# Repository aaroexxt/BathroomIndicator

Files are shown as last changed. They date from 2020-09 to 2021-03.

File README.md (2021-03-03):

# BathroomIndicator
 BLISS - Bathroom Location and Indication Security System aka an overcomplicated way to prevent accidental walk-ins, and a great PCB learning project!

## Design Intent
I built this mostly to practice my PCB design and layout skills, but it's actually quite cool in person. Basically, it's designed to be a comprehensive system for people who have to share space to have a way to tell others that they're busy. I've installed a set of these on a bathroom I share with my sister (who thought that was a good idea?) so that we can both know when somebody else is using the bathroom.

## Pictures

Version 1
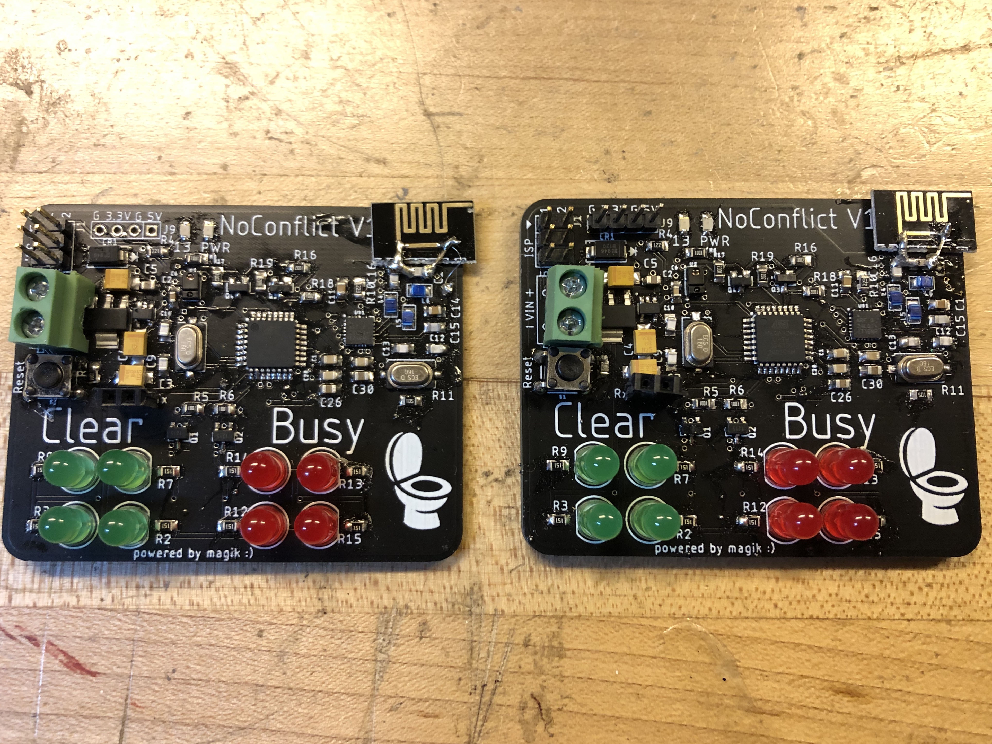
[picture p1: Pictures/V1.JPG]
Version 1


Version 2
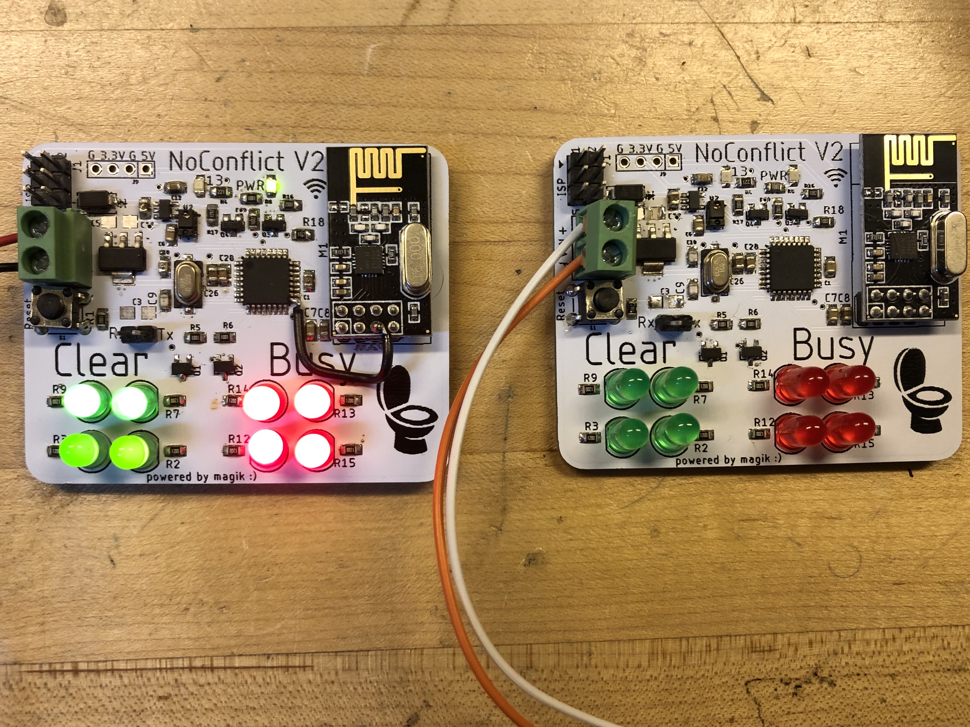
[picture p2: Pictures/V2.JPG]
Version 2


## Renderings

Top - Version 2
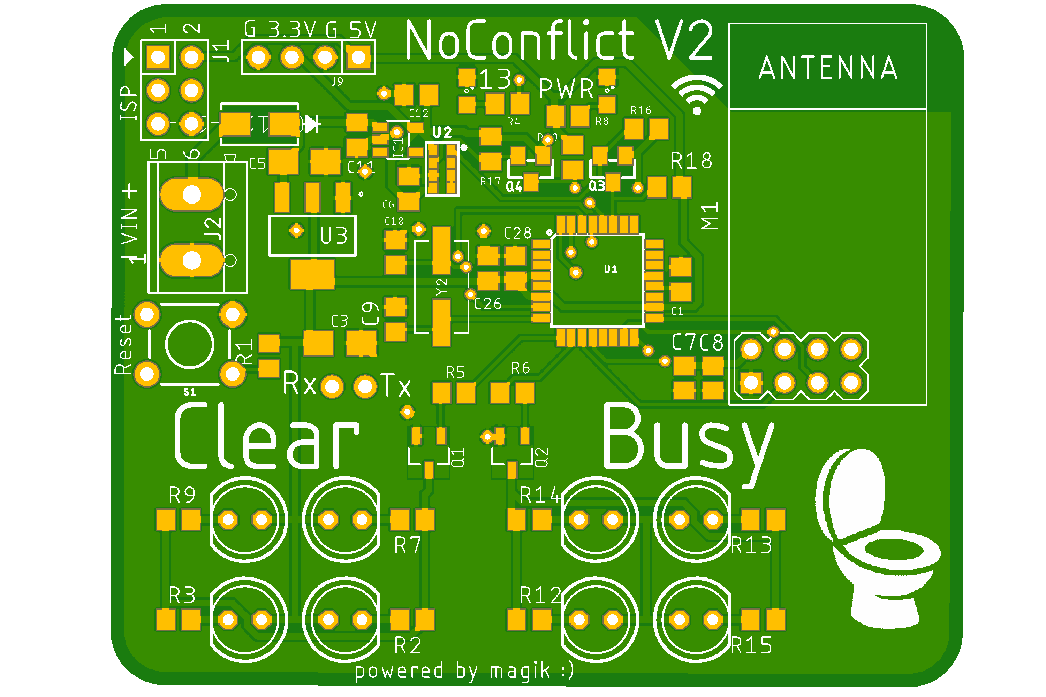
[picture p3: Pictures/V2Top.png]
Version 2 Top


Bottom - Version 2
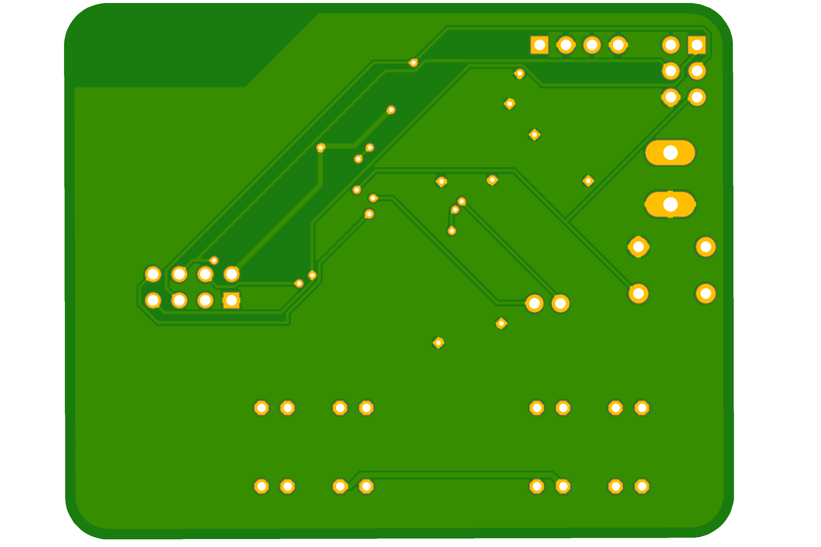
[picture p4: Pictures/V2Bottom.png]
Version 2 Bottom


### Design Notes

The major difference between versions 1 and 2 is that Version 1 had a custom radio based on the NRF24L01+ radio by Nordic Semiconductor, while this was replaced with a premade module in Version 2 because of my lack of experience with antenna design (1 foot range on my custom one vs _30_ feet on the premade module). Other than that, it worked well. I also had some issues with the 3.3v regulator schematic in V1 (incorrect schematic for EN pin) but this was solved in version 2.

### By Aaron Becker

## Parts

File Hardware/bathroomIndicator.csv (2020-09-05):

Qty | Value | Device | Package | Parts | Description | ARROW_ELECTRONICS-PURCHASE-URL | AUTOMOTIVE | AVAILABILITY | BUILT_BY | CENTROID_NOT_SPECIFIED | COLLECTOR_BASE_VOLTAGE | COLLECTOR_EMITTER_BREAKDOWN_VOLTAGE | COLLECTOR_EMITTER_SATURATION_VOLTAGE | COLLECTOR_EMITTER_VOLTAGE | DATASHEET | DESCRIPTION | DEVICE_CLASS_L1 | DEVICE_CLASS_L2 | DEVICE_CLASS_L3 | DIGIKEY-PURCHASE-URL | DIGIKEY_DESCRIPTION | DIGIKEY_PART_NUMBER | EMITTER_BASE_VOLTAGE | FOOTPRINT_PARAMETERS_1 | FOOTPRINT_PARAMETERS_2 | FOOTPRINT_PARAMETERS_3 | FOOTPRINT_VARIANT_NAME_0 | FOOTPRINT_VARIANT_NAME_1 | FOOTPRINT_VARIANT_NAME_2 | FOOTPRINT_VARIANT_NAME_3 | HEIGHT | HFE_MAX | HFE_MIN | HFE_TESTIC | HFE_TESTVCE | IPC_LAND_PATTERN_NAME | LEAD_FREE | MANUFACTURER_PART_NUMBER | MAX_COLLECTOR_CURRENT | MAX_JUNCTION_TEMP | MF | MFG_PACKAGE_IDENT | MFG_PACKAGE_IDENT_COMPONENT_ID | MFG_PACKAGE_IDENT_DATE | MFG_PACKAGE_IDENT_REV | MOUSER-PURCHASE-URL | MOUSER_DESCRIPTION | MOUSER_PART_NUMBER | MP | MPN | NUMBER_OF_ELEMENTS | NUMBER_OF_NPN | OC_FARNELL | OC_NEWARK | PACKAGE | POPULARITY | POWER_DISSIPATION | PREFIX | PRICE
1 |  | HEADER-1X2ROUND | 1X02_ROUND | JP1 | PIN HEADER
8 |  | LED5MM | LED5MM | LED1, LED2, LED5, LED6, LED7, LED8, LED9, LED10 | LED |  |  |  |  |  |  |  |  |  |  |  |  |  |  |  |  |  |  |  |  |  |  |  |  |  |  |  |  |  |  |  |  |  |  |  |  |  |  |  |  |  |  |  |  |  |  |  |  |  |  | 93
2 |  | LEDSML0805 | SML0805 | LED3, LED4 | LED |  |  |  |  |  |  |  |  |  |  |  |  |  |  |  |  |  |  |  |  |  |  |  |  |  |  |  |  |  |  |  |  |  |  |  |  |  |  |  |  |  |  |  |  |  |  |  |  |  |  | 17
4 | 0.1uF | C-USC0805 | C0805 | C1, C6, C8, C28 | CAPACITOR, American symbol |  |  |  |  |  |  |  |  |  |  |  |  |  |  |  |  |  |  |  |  |  |  |  |  |  |  |  |  |  |  |  |  |  |  |  |  |  |  |  |  |  |  |  |  |  |  |  |  |  |  | 63
1 | 1 uF | C-USC0805 | C0805 | C11 | CAPACITOR, American symbol |  |  |  |  |  |  |  |  |  |  |  |  |  |  |  |  |  |  |  |  |  |  |  |  |  |  |  |  |  |  |  |  |  |  |  |  |  |  |  |  |  |  |  |  |  |  |  |  |  |  | 63
5 | 10k | R-US_R0805 | R0805 | R1, R16, R17, R18, R19 | RESISTOR, American symbol |  |  |  |  |  |  |  |  |  |  |  |  |  |  |  |  |  |  |  |  |  |  |  |  |  |  |  |  |  |  |  |  |  |  |  |  |  |  |  |  |  |  |  |  |  |  |  |  |  |  | 85
2 | 10uF | CPOL-USB/3528-21W | B/3528-21W | C3, C5 | POLARIZED CAPACITOR, American symbol |  |  |  |  |  |  |  |  |  |  |  |  |  |  |  |  |  |  |  |  |  |  |  |  |  |  |  |  |  |  |  |  |  |  |  |  |  |  |  |  |  |  |  |  |  |  |  |  |  |  | 3
8 | 120 | R-US_R0805 | R0805 | R2, R3, R7, R9, R12, R13, R14, R15 | RESISTOR, American symbol |  |  |  |  |  |  |  |  |  |  |  |  |  |  |  |  |  |  |  |  |  |  |  |  |  |  |  |  |  |  |  |  |  |  |  |  |  |  |  |  |  |  |  |  |  |  |  |  |  |  | 85
3 | 1k | R-US_R0805 | R0805 | R5, R6, R8 | RESISTOR, American symbol |  |  |  |  |  |  |  |  |  |  |  |  |  |  |  |  |  |  |  |  |  |  |  |  |  |  |  |  |  |  |  |  |  |  |  |  |  |  |  |  |  |  |  |  |  |  |  |  |  |  | 85
2 | 1uF | C-USC0805 | C0805 | C7, C26 | CAPACITOR, American symbol |  |  |  |  |  |  |  |  |  |  |  |  |  |  |  |  |  |  |  |  |  |  |  |  |  |  |  |  |  |  |  |  |  |  |  |  |  |  |  |  |  |  |  |  |  |  |  |  |  |  | 63
1 | 2.2 uF | C-USC0805 | C0805 | C12 | CAPACITOR, American symbol |  |  |  |  |  |  |  |  |  |  |  |  |  |  |  |  |  |  |  |  |  |  |  |  |  |  |  |  |  |  |  |  |  |  |  |  |  |  |  |  |  |  |  |  |  |  |  |  |  |  | 63
2 | 20pF | C-USC0805 | C0805 | C9, C10 | CAPACITOR, American symbol |  |  |  |  |  |  |  |  |  |  |  |  |  |  |  |  |  |  |  |  |  |  |  |  |  |  |  |  |  |  |  |  |  |  |  |  |  |  |  |  |  |  |  |  |  |  |  |  |  |  | 63
1 | 220 | R-US_R0805 | R0805 | R4 | RESISTOR, American symbol |  |  |  |  |  |  |  |  |  |  |  |  |  |  |  |  |  |  |  |  |  |  |  |  |  |  |  |  |  |  |  |  |  |  |  |  |  |  |  |  |  |  |  |  |  |  |  |  |  |  | 85
1 | APDS-9960 | APDS-9960 | APDS-9960 | U2 | Avago APDS-9960 Digital Proximity, Ambient Light, RGB, and Gesture Sensor.
1 | ATMEGA328P_TQFP | ATMEGA328P_TQFP | TQFP32-08 | U1 | Popular 328P in QFP
1 | B120-13-F | B120-13-F | SMA_DIO | CR1 |  |  |  |  | EMA_UL_Team |  |  |  |  |  |  |  |  |  |  |  |  |  |  |  |  |  |  |  |  |  |  |  |  |  |  |  |  | B120-13-F
2 | BSS138 | MOSFET-NWIDE | SOT23-WIDE | Q3, Q4 | N-Channel Mosfet
1 | CON_HEADER_1X04 | CON_HEADER_1X04 | M1X4 | J9
1 | CON_HEADER_PRG_AVR_ICSP-PTH | CON_HEADER_PRG_AVR_ICSP-PTH | HEADER_PRG_2X03 | J1 | 2x3 AVR ICSP programming header
1 | CON_TERMINAL_BLOCK_02-5MM | CON_TERMINAL_BLOCK_02-5MM | TERMINAL_BLOCK_2P_5 | J2 | 2 poles wire to board terminal block
1 | ECS-160-20-3X-TR | ECS-160-20-3X-TR | XTAL_ECS-160-20-3X-TR | Y2 | SMD QUARTZ CRYSTAL | https://snapeda.com/shop?store=Arrow+Electronics&id=561589 |  | Unavailable |  |  |  |  |  |  |  | 16MHz ±30ppm Crystal 20pF 50 Ohms HC-49/US |  |  |  | https://snapeda.com/shop?store=DigiKey&id=561589 |  |  |  |  |  |  |  |  |  |  |  |  |  |  |  |  |  |  |  |  | ECS Inc. |  |  |  |  | https://snapeda.com/shop?store=Mouser&id=561589 |  |  | ECS-160-20-3X-TR |  |  |  |  |  | HC49/US ECS International |  |  |  | None
1 | MOMENTARY-SWITCH-SPST-PTH-6.0MM | MOMENTARY-SWITCH-SPST-PTH-6.0MM | TACTILE_SWITCH_PTH_6.0MM | S1 | Momentary Switch (Pushbutton) - SPST
1 | NCP1117ST50T3G | NCP1117ST50T3G | SOT230P700X180-4N | U3 | 1.0 A Low-Dropout Positive ,Fixed and Adjustable,Voltage Regulators |  |  | Unavailable |  |  |  |  |  |  |  | Linear Voltage Regulator IC 1 Output 1A SOT-223 |  |  |  | https://snapeda.com/shop?store=DigiKey&id=836318 |  |  |  |  |  |  |  |  |  |  |  |  |  |  |  |  |  |  |  |  | ON Semiconductor |  |  |  |  | https://snapeda.com/shop?store=Mouser&id=836318 |  |  | NCP1117ST50T3G |  |  |  |  |  | SOT-223 ON Semiconductor |  |  |  | None
2 | STMICROELECTRONICS_2STR1215STMICROELECTRONICS_2STR1215_0_0 | STMICROELECTRONICS_2STR1215STMICROELECTRONICS_2STR1215_0_0 | STMICROELECTRONICS_2STR1215_0 | Q1, Q2 | Bipolar (BJT) Transistor NPN 15V 1.5A 500mW Surface Mount SOT-23-3 |  | No |  |  | No | 15V | 15V | 0.4V | 15V | https://www.st.com/resource/en/datasheet/2str1215.pdf |  | Discrete Semiconductors | Transistors | BJTs |  | TRANS NPN 15V 1.5A SOT-23 | 497-6205-1-ND | 5V | {fp_type":"SOT23","params":{"N":{"default":"3","long name":"Number of leads","type":"multichoice","short name":"N"},"A":{"nom":false,"long name":"Height","min":false,"max":1250000,"short name":"A","type":"measurement"},"A1":{"nom":75000,"long name":"Package clearance","min":0,"max":150000,"short name":"A1","type":"measurement"},"A2":{"nom":1100000,"long name":"Package height","min":1000000,"max":1200000,"short name":"A2","type":"measurement"},"D":{"nom":2926000,"long name":"Package length","min":2826000,"max":3026000,"short name":"D","type":"measurement"},"E":{"nom":2800000,"long name":"Width /w leads","min":2600000,"max":3000000,"short name":"E","type":"measurement"},"E1":{"nom":1625000,"long name":"Package width","min":1526000,"max":1726000,"short name":"E1","type":"measurement"},"B":{"nom":430000,"long name":"Lead width","min":360000,"max":500000,"short name":"B","type":"measurement"},"C":{"nom":170000,"long name":"Lead thickness","min":140000,"max":200000,"short name":"C","type":"measurement"},"L":{"nom":450000,"long name":"Lead foot length","min":350000,"max":600000,"short name":"L","type":"measurement"},"e":{"nom":950000,"long name":"Lead pitch","min":null,"max":null,"short name":"e","type":"measurement"},"PHI":{"nom":false,"long name":"Lead angle","min":0,"max":8000000,"short name":"PHI","type":"measurement"},"offset x":{"nom":0,"long name":"X Center offset","min":null,"max":null,"short name":"offset x","type":"measurement"},"offset y":{"nom":0,"long name":"Y Center 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 | {fp_type":"SOT23","params":{"N":{"default":"3","long name":"Number of leads","type":"multichoice","short name":"N"},"A":{"nom":false,"long name":"Height","min":false,"max":1250000,"short name":"A","type":"measurement"},"A1":{"nom":75000,"long name":"Package clearance","min":0,"max":150000,"short name":"A1","type":"measurement"},"A2":{"nom":1100000,"long name":"Package height","min":1000000,"max":1200000,"short name":"A2","type":"measurement"},"D":{"nom":2926000,"long name":"Package length","min":2826000,"max":3026000,"short name":"D","type":"measurement"},"E":{"nom":2800000,"long name":"Width /w leads","min":2600000,"max":3000000,"short name":"E","type":"measurement"},"E1":{"nom":1625000,"long name":"Package width","min":1526000,"max":1726000,"short name":"E1","type":"measurement"},"B":{"nom":430000,"long name":"Lead width","min":360000,"max":500000,"short name":"B","type":"measurement"},"C":{"nom":170000,"long name":"Lead thickness","min":140000,"max":200000,"short name":"C","type":"measurement"},"L":{"nom":450000,"long name":"Lead foot length","min":350000,"max":600000,"short name":"L","type":"measurement"},"e":{"nom":950000,"long name":"Lead pitch","min":null,"max":null,"short name":"e","type":"measurement"},"PHI":{"nom":false,"long name":"Lead angle","min":0,"max":8000000,"short name":"PHI","type":"measurement"},"offset x":{"nom":0,"long name":"X Center offset","min":null,"max":null,"short name":"offset x","type":"measurement"},"offset y":{"nom":0,"long name":"Y Center 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 | {fp_type":"SOT23","params":{"N":{"default":"3","long name":"Number of leads","type":"multichoice","short name":"N"},"A":{"nom":false,"long name":"Height","min":false,"max":1250000,"short name":"A","type":"measurement"},"A1":{"nom":75000,"long name":"Package clearance","min":0,"max":150000,"short name":"A1","type":"measurement"},"A2":{"nom":1100000,"long name":"Package height","min":1000000,"max":1200000,"short name":"A2","type":"measurement"},"D":{"nom":2926000,"long name":"Package length","min":2826000,"max":3026000,"short name":"D","type":"measurement"},"E":{"nom":2800000,"long name":"Width /w leads","min":2600000,"max":3000000,"short name":"E","type":"measurement"},"E1":{"nom":1625000,"long name":"Package width","min":1526000,"max":1726000,"short name":"E1","type":"measurement"},"B":{"nom":430000,"long name":"Lead width","min":360000,"max":500000,"short name":"B","type":"measurement"},"C":{"nom":170000,"long name":"Lead thickness","min":140000,"max":200000,"short name":"C","type":"measurement"},"L":{"nom":450000,"long name":"Lead foot length","min":350000,"max":600000,"short name":"L","type":"measurement"},"e":{"nom":950000,"long name":"Lead pitch","min":null,"max":null,"short name":"e","type":"measurement"},"PHI":{"nom":false,"long name":"Lead angle","min":0,"max":8000000,"short name":"PHI","type":"measurement"},"offset x":{"nom":0,"long name":"X Center offset","min":null,"max":null,"short name":"offset x","type":"measurement"},"offset y":{"nom":0,"long name":"Y Center 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 | Recommended_Land_Pattern | IPC_A | IPC_B | IPC_C | 1.25mm | 560 | 200 | 0.5A | 2V | SOT95P280X125-3 | Yes |  | 1.5A | +150°C | STMicroelectronics | SOT23_8162275 | 8e1c602943959e66 | 0 | 3 |  | Bipolar Transistors - BJT Lo Vltg FAST SWITCH Hi GAIN PNP | 511-2STR1215 |  | 2STR1215 | 1 | 1 |  |  | SOT-23 |  | 0.5W | Q
1 | TPS70933DBV | TPS70933DBV | SOT23-5 | IC1 | TPS709xx 150-mA, 30-V, 1-μA IQ Voltage Regulators with Enable |  |  |  |  |  |  |  |  |  |  |  |  |  |  |  |  |  |  |  |  |  |  |  |  |  |  |  |  |  |  |  |  |  |  |  | Texas Instruments |  |  |  |  |  |  |  |  | TPS70933DBVT |  |  | 2382995 | 37X8895
1 | WIRELESS-NRF24L01 | WIRELESS-NRF24L01 | WIRELESS-NRF24L01 | M1 | 2.4 GHz Wireless Module based on NRF24L01 chip
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

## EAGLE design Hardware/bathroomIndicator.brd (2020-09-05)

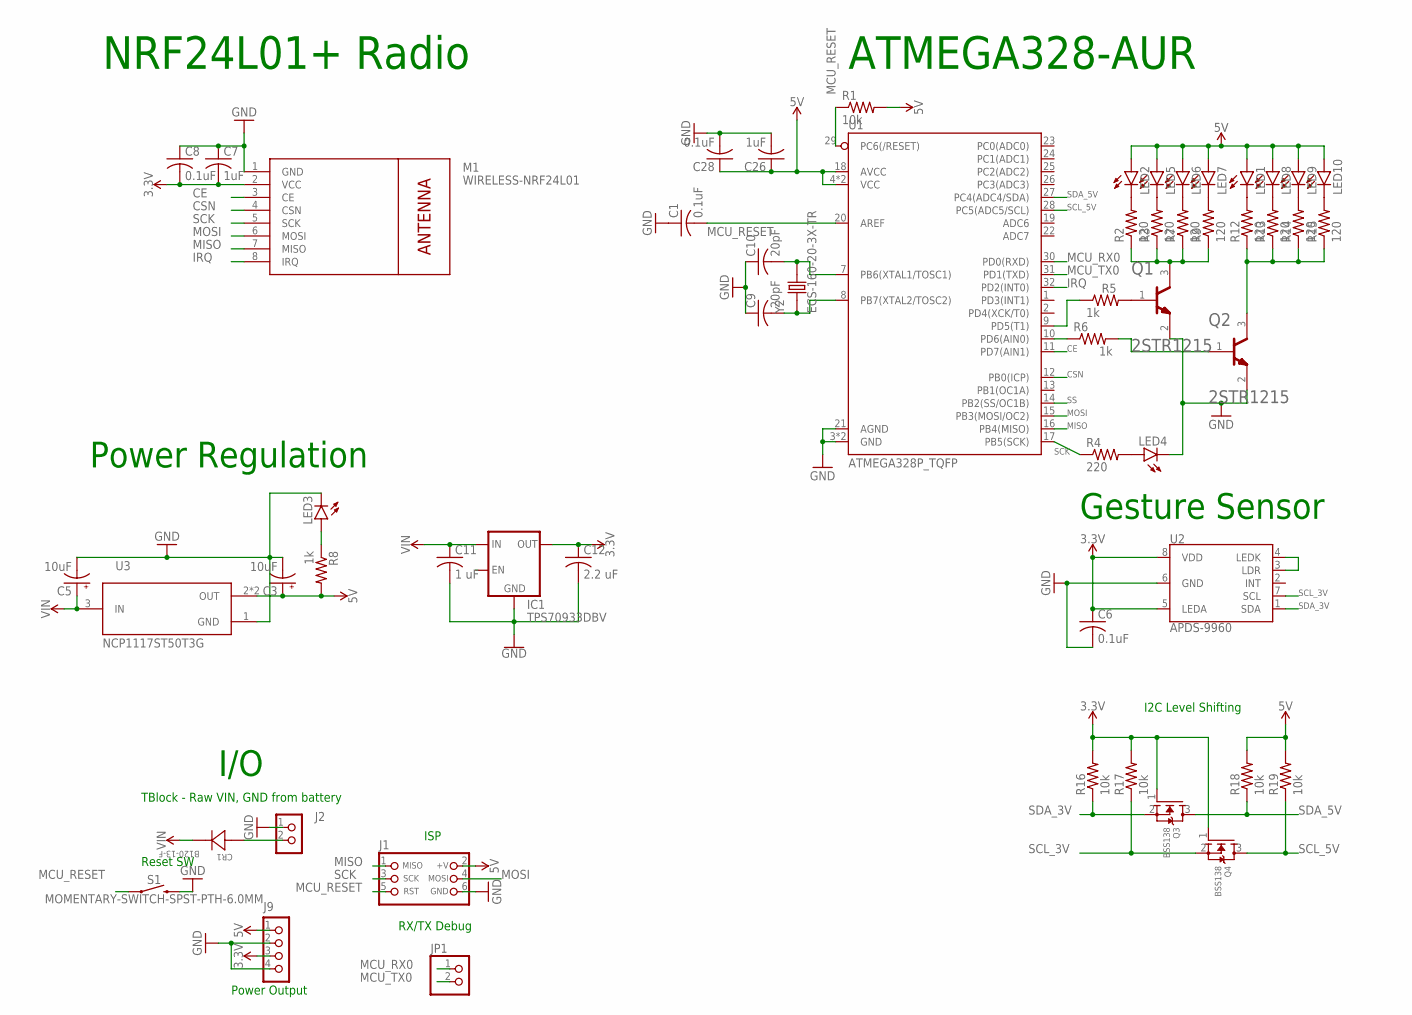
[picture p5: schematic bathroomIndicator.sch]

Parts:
C1, C6, C8, C28: 0.1uF; C0805
C3, C5: 10uF; B/3528-21W
C7, C26: 1uF; C0805
C9, C10: 20pF; C0805
C11: 1 uF; C0805
C12: 2.2 uF; C0805
CR1: B120-13-F; SMA_DIO
IC1: TPS70933DBV; SOT23-5
J1: CON_HEADER_PRG_AVR_ICSP-PTH; HEADER_PRG_2X03
J2: CON_TERMINAL_BLOCK_02-5MM; TERMINAL_BLOCK_2P_5
J9: CON_HEADER_1X04; M1X4
JP1: HEADER-1X2ROUND; 1X02_ROUND
LED1, LED2, LED5, LED6, LED7, LED8, LED9, LED10: LED5MM
LED3, LED4: LEDSML0805; SML0805
M1: WIRELESS-NRF24L01
Q1, Q2: STMICROELECTRONICS_2STR1215STMICROELECTRONICS_2ST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; STMICROELECTRONICS_2STR1215_0
Q3, Q4: BSS138; SOT23-WIDE
R1, R16, R17, R18, R19: 10k; R0805
R2, R3, R7, R9, R12, R13, R14, R15: 120; R0805
R4: 220; R0805
R5, R6, R8: 1k; R0805
S1: MOMENTARY-SWITCH-SPST-PTH-6.0MM; TACTILE_SWITCH_PTH_6.0MM
U1: ATMEGA328P_TQFP; TQFP32-08
U2: APDS-9960
U3: NCP1117ST50T3G; SOT230P700X180-4N
Y2: ECS-160-20-3X-TR; XTAL_ECS-160-20-3X-TR

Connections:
3.3V: C6.1, C7.2, C8.2, C12.1, IC1.5 (OUT), J9.3, M1.2 (VCC), Q3.1 (G), Q4.1 (G), R16.2, R17.2, U2.5 (LEDA), U2.8 (VDD)
5V: C3.+, C26.1, C28.1, J1.2 (+V), J9.1, LED1.A, LED2.A, LED5.A, LED6.A, LED7.A, LED8.A, LED9.A, LED10.A, R1.2, R8.2, R18.2, R19.2, U1.4 (VCC), U1.6 (VCC), U1.18 (AVCC), U3.2 (OUT), U3.4 (OUT)
CE: M1.3 (CE), U1.11 (PD7(AIN1))
CSN: M1.4 (CSN), U1.12 (PB0(ICP))
GND: C1.1, C3.-, C5.-, C6.2, C7.1, C8.1, C9.1, C10.1, C11.2, C12.2, C26.2, C28.2, IC1.2 (GND), J1.6 (GND), J2.1, J9.2, J9.4, LED3.C, LED4.C, M1.1 (GND), Q1.2 (E), Q2.2 (E), S1.3 (2), U1.3 (GND), U1.5 (GND), U1.21 (AGND), U2.6 (GND), U3.1 (GND)
IRQ: M1.8 (IRQ), U1.32 (PD2(INT0))
MCU_RESET: J1.5 (RST), R1.1, S1.1, U1.29 (PC6(/RESET))
MCU_RX0: JP1.1, U1.30 (PD0(RXD))
MCU_TX0: JP1.2, U1.31 (PD1(TXD))
MISO: J1.1 (MISO), M1.7 (MISO), U1.16 (PB4(MISO))
MOSI: J1.4 (MOSI), M1.6 (MOSI), U1.15 (PB3(MOSI/OC2))
unnamed: LED2.K (C), R2.2
unnamed: LED5.K (C), R3.2
unnamed: C1.2, U1.20 (AREF)
unnamed: LED6.K (C), R7.2
unnamed: R5.1, U1.9 (PD5(T1))
unnamed: LED7.K (C), R9.2
unnamed: LED4.A, R4.2
unnamed: Q2.1 (B), R6.2
unnamed: R6.1, U1.10 (PD6(AIN0))
unnamed: LED3.A, R8.1
unnamed: Q1.1 (B), R5.2
unnamed: C9.2, U1.8 (PB7(XTAL2/TOSC2)), Y2.1
unnamed: C10.2, U1.7 (PB6(XTAL1/TOSC1)), Y2.2
unnamed: U2.3 (LDR), U2.4 (LEDK)
unnamed: LED1.K (C), R12.2
unnamed: LED8.K (C), R13.2
unnamed: LED9.K (C), R14.2
unnamed: LED10.K (C), R15.2
unnamed: Q1.3 (C), R2.1, R3.1, R7.1, R9.1
unnamed: Q2.3 (C), R12.1, R13.1, R14.1, R15.1
unnamed: CR1.2, J2.2
SCK: J1.3 (SCK), M1.5 (SCK), R4.1, U1.17 (PB5(SCK))
SCL_3V: Q4.2 (S), R17.1, U2.7 (SCL)
SCL_5V: Q4.3 (D), R19.1, U1.28 (PC5(ADC5/SCL))
SDA_3V: Q3.2 (S), R16.1, U2.1 (SDA)
SDA_5V: Q3.3 (D), R18.1, U1.27 (PC4(ADC4/SDA))
SS: U1.14 (PB2(SS/OC1B))
VIN: C5.+, C11.1, CR1.1, IC1.1 (IN), U3.3 (IN)

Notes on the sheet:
TBlock - Raw VIN, GND from battery
NRF24L01+ Radio
ATMEGA328-AUR
Power Regulation
I/O
Gesture Sensor
I2C Level Shifting
RX/TX Debug
ISP
Reset SW
Power Output

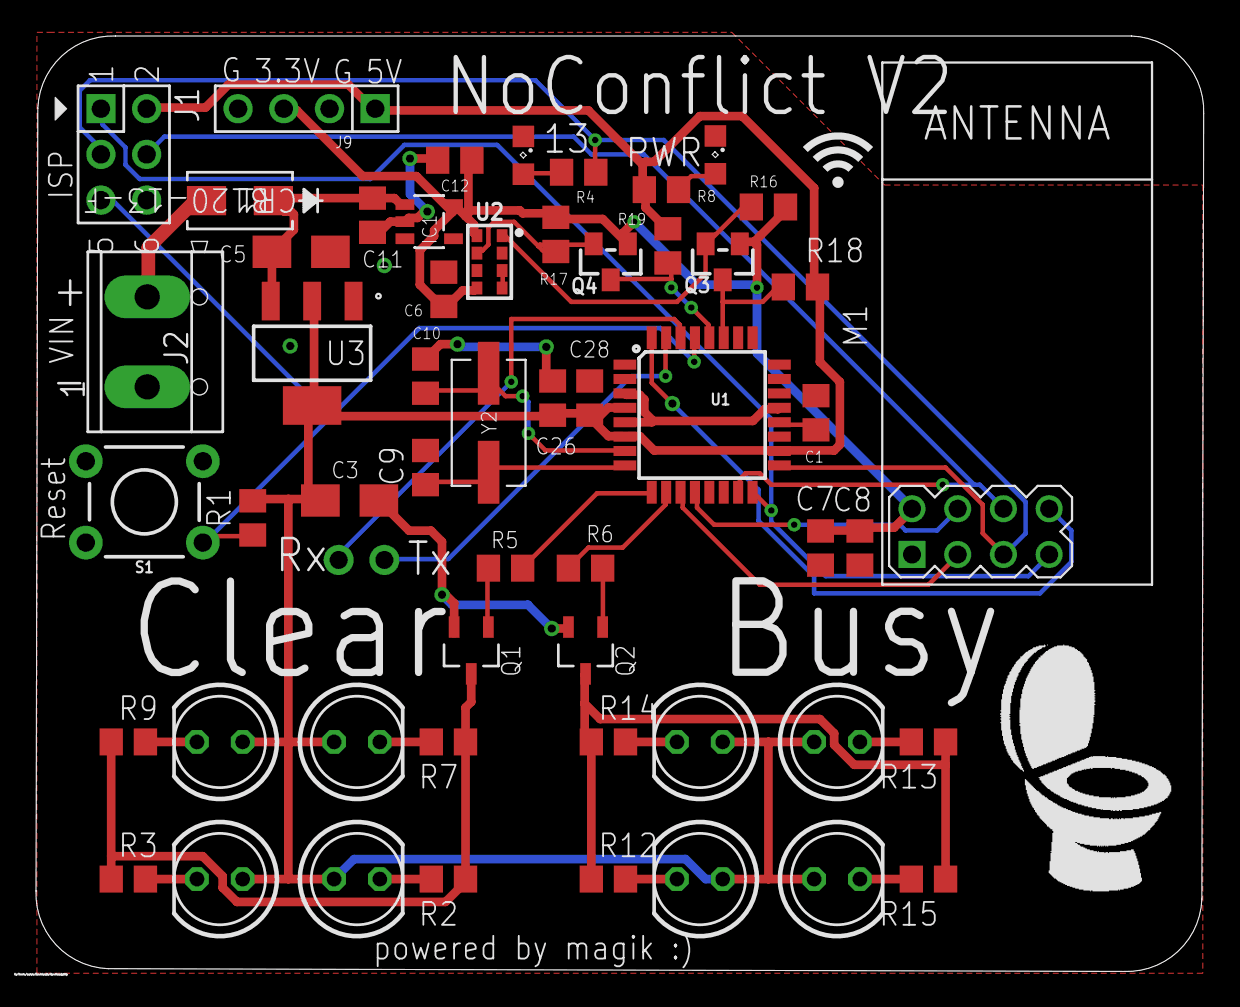
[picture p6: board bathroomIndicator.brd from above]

Board: 2 copper layers, 64.9 x 52.0 mm, 55 parts (0 on the bottom side), 38 nets.

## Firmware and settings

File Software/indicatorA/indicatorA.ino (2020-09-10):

//IndicatorA.ino by Aaron Becker

#include <Arduino_APDS9960.h>
#include <SPI.h>
#include <nRF24L01.h>
#include <RF24.h>
#include <avr/power.h>

RF24 radio(7, 8); // CE, CSN
const byte addresses[][6] = {"00003", "00002"};
//TODO sleep mode and IRQ pin interrupts
#define PROX_THRESH 20
#define CLEAR 5
#define BUSY 6
#define IRQ 2

const boolean debug = false;

boolean radioListening = false;
void setup() {
	Serial.begin(9600);
	while (!Serial); // Wait for serial monitor to open

	boolean error = false;
	int errorDelay = 100;
	int okDelay = 50;
	if (!APDS.begin()) {
		Serial.println("Error initializing APDS9960 sensor.");
		error = true;
		errorDelay = 50;
	}
	APDS.setGestureSensitivity(85);

	//Power saving stuff
	power_adc_disable();
	power_usart0_disable();

	//Radio stuff
  	radio.begin();
	radio.setPALevel(RF24_PA_MAX); //max because we don't want to lose connection
	radio.setRetries(3,3); // delay, count
	radio.openWritingPipe(addresses[1]);
	radio.openReadingPipe(1, addresses[0]); //set address to recieve data
	radio.maskIRQ(1,1,0);
	attachInterrupt(digitalPinToInterrupt(IRQ), recv, FALLING);
	radioTransmitMode();
	radio.stopListening();

	  pinMode(CLEAR, OUTPUT);
	  pinMode(BUSY, OUTPUT);

	while (error) {
		analogWrite(CLEAR, 32);
		digitalWrite(BUSY, LOW);
		delay(errorDelay);
		digitalWrite(CLEAR, LOW);
		analogWrite(BUSY, 32);
		delay(errorDelay);
	}

	Serial.println("IndicatorA starting");

	analogWrite(CLEAR, 32);
	digitalWrite(BUSY, LOW);
	delay(okDelay);
	digitalWrite(CLEAR, LOW);
	analogWrite(BUSY, 32);
	delay(okDelay);
	analogWrite(CLEAR, 32);
	digitalWrite(BUSY, LOW);
	delay(okDelay);
	digitalWrite(CLEAR, LOW);
	analogWrite(BUSY, 32);
	delay(okDelay);
	digitalWrite(CLEAR, LOW);
	digitalWrite(BUSY, LOW);
	delay(500);

}

int proximity = 0;
unsigned long lastUpdate = 0;
int currentState = 0;
int roomClear = 0;
boolean toggle = false;

unsigned long lastRecvTime = 0;
unsigned long lastStatusMillis = 0;

void loop() {
	switch (currentState) {
		case 0:
			if (millis() - lastUpdate > 100) {
				if (!toggle) {
					analogWrite(CLEAR, 32);
					analogWrite(BUSY, 32);
					toggle = true;
				} else {
					digitalWrite(CLEAR, LOW);
					digitalWrite(BUSY, LOW);
					toggle = false;
				}
				send(200);
				lastUpdate = millis();
			}
			break;
		case 1:
			if (proximity < PROX_THRESH) {
				if (roomClear) {
					analogWrite(CLEAR, 32);
					digitalWrite(BUSY, LOW);
				} else {
					digitalWrite(CLEAR, LOW);
					analogWrite(BUSY, 32);
				}
				lastUpdate = millis();
			} else { //maybe add a thing where u cant swipe after taking hand away
				digitalWrite(CLEAR, LOW);
				digitalWrite(BUSY, LOW);
				toggle = true;
			}

			if (millis() - lastUpdate > 1000 && toggle) {
				digitalWrite(CLEAR, LOW);
				digitalWrite(BUSY, LOW);
				toggle = false;
			}
			break;
	}

	// Check if a proximity reading is available.
	if (APDS.proximityAvailable()) {
		proximity = APDS.readProximity();
	}

	// check if a gesture reading is available
	if (APDS.gestureAvailable()) {
		int gesture = APDS.readGesture();
		switch (gesture) {
		  case GESTURE_UP:
		    roomClear = 1;
		    send(roomClear);
		    lights(true,2);
		    break;

		  case GESTURE_DOWN:
		    roomClear = 0;
		    send(roomClear);
		    lights(false,2);
		    break;
		}
	}
	if (millis() - lastStatusMillis > 500) {
		send(200);
		send(roomClear);
		if (millis() - lastRecvTime >= 15000) {
			currentState = 0;
		}
		lastStatusMillis = millis();
	}
}

void send(int dat) {
	radioTransmitMode();
	/*if (dat != 200) {
		Serial.print("S: ");
		Serial.println(dat);
	}*/
    radio.write(&dat, sizeof(dat));
    radioRecieveMode();
}

void recv() {
	radioRecieveMode();
	if (radio.available()) {
		int med = 0;
		radio.read(&med, sizeof(med));

		/*if (med != 200) {
			Serial.print("R: ");
			Serial.println(med);
		}*/
		if (med < 200) {
			roomClear = med;
		}
		lastRecvTime = millis();
		currentState = 1;
	}
}

void radioRecieveMode() {
  if (!radioListening) { //if we're not listening
    radio.startListening();
    radioListening = true;
  }
}

void radioTransmitMode() {
  if (radioListening) {
    radio.stopListening();
    radioListening = false;
  }
}

void lights(boolean state, int count) {
	send(roomClear);
	if (state) {
		analogWrite(CLEAR, 32);
		digitalWrite(BUSY, LOW);
	} else {
		digitalWrite(CLEAR, LOW);
		analogWrite(BUSY, 32);
	}
	send(roomClear);

	for (int i = 0; i<count; i++) {
		delay(100);
		send(roomClear);
		digitalWrite(CLEAR, LOW);
		digitalWrite(BUSY, LOW);
		delay(100);
		send(roomClear);
		if (state) {
			analogWrite(CLEAR, 32);
			digitalWrite(BUSY, LOW);
		} else {
			digitalWrite(CLEAR, LOW);
			analogWrite(BUSY, 32);
		}
	}
}

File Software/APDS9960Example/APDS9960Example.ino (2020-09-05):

/*
  APDS9960 - All sensor data from APDS9960

  This example reads all data from the on-board APDS9960 sensor of the
  Nano 33 BLE Sense:
   - color RGB (red, green, blue)
   - proximity
   - gesture
  and prints updates to the Serial Monitor every 100 ms.

  The circuit:
  - Arduino Nano 33 BLE Sense

  This example code is in the public domain.
*/

#include <Arduino_APDS9960.h>

void setup() {
  Serial.begin(9600);
  while (!Serial); // Wait for serial monitor to open

  if (!APDS.begin()) {
    Serial.println("Error initializing APDS9960 sensor.");
    while (true){
      digitalWrite(5, HIGH);
  digitalWrite(6, HIGH);
  delay(250);
  digitalWrite(5, LOW);
  digitalWrite(6, LOW);
  delay(250);
      // Stop forever
    }
  }

  digitalWrite(5, HIGH);
  digitalWrite(6, HIGH);
  delay(500);
  digitalWrite(5, LOW);
  digitalWrite(6, LOW);
}

int proximity = 0;
int r = 0, g = 0, b = 0;
unsigned long lastUpdate = 0;

void loop() {

  // Check if a proximity reading is available.
  if (APDS.proximityAvailable()) {
    proximity = APDS.readProximity();
  }

  // check if a gesture reading is available
  if (APDS.gestureAvailable()) {
    int gesture = APDS.readGesture();
    switch (gesture) {
      case GESTURE_UP:
        Serial.println("Detected UP gesture");
        digitalWrite(5, HIGH);
        digitalWrite(6, LOW);
        break;

      case GESTURE_DOWN:
        Serial.println("Detected DOWN gesture");
        digitalWrite(6, HIGH);
        digitalWrite(5, LOW);
        break;

      case GESTURE_LEFT:
        Serial.println("Detected LEFT gesture");
        break;

      case GESTURE_RIGHT:
        Serial.println("Detected RIGHT gesture");
        break;

      default:
        // ignore
        break;
    }
  }

  // check if a color reading is available
  if (APDS.colorAvailable()) {
    APDS.readColor(r, g, b);
  }

  // Print updates every 100ms
  if (millis() - lastUpdate > 100) {
    lastUpdate = millis();
    Serial.print("PR=");
    Serial.print(proximity);
    Serial.print(" rgb=");
    Serial.print(r);
    Serial.print(",");
    Serial.print(g);
    Serial.print(",");
    Serial.println(b);
  }
}

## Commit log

2020-09-05 upload all info
    [bathroomIndicator.brd, bathroomIndicator.csv, bathroomIndicator.sch]
2020-09-09 added reset to clear after 20min feature
    [indicatorB.ino]

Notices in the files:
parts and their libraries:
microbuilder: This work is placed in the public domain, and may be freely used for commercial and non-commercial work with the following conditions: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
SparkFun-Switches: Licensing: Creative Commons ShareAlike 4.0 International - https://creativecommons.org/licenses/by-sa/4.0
